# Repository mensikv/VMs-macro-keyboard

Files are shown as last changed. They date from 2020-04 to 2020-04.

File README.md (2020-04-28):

# VM's macro keyboard
This project is developed for Arduino Micro boards and it functions as a **macro keyboard with rotary encoder**. Eight mechanical cherry MX keys can be assigned various functions (writing text, combination and sequences of key codes, multimedia and mouse functions). Rotary encoder supports turning, click and double click.

## Features
* up to 4 keys codes sent at once
* sequence of maximum 16 length of separate key commands
* modifier key to change the default behavior of rotary encoder
* STL files for case
* all keys are directly connected to GPIOs, so no diodes are required
* can emulate keyboard, multimedia key, mouse and system commands

This project is inspired by and some code is taken from [Control volume knob by Prusa](https://blog.prusaprinters.org/3d-print-an-oversized-media-control-volume-knob-arduino-basics/).

## Prerequisites
### Hardware
* 8x [Cherry MX](https://www.aliexpress.com/item/32900957560.html) - I have used red ones
* 1x [25cm micro USB cable](https://www.aliexpress.com/item/32958208619.html) - you can of course use any micro USB cable
* 1x [Arduino Pro Micro 5V](https://www.aliexpress.com/item/32785518952.html) - as the board is powered from the USB, ie. with 5V, you can solder the J1 solder joint to bypass the LDO
* 1x [rotary encoder](https://www.aliexpress.com/item/1000001872933.html) - make sure it has thread to secure it on the case
* Optional - [sillicone wires](https://www.aliexpress.com/item/32872439317.html) - in comparison to my old wires, these are angel's stuff. I have used AWG26, but I suggest to use AWG 28, there are no big currents.

Connection between the components:
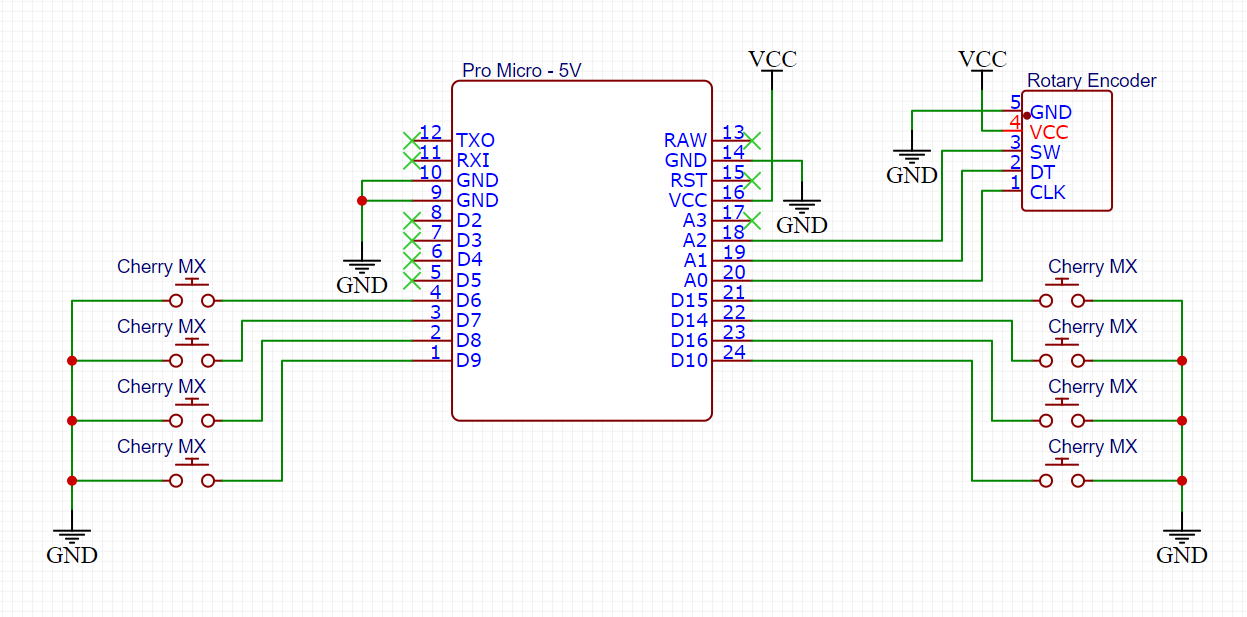
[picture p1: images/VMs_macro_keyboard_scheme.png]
Scheme


### Software
Project was tested with following version:
* Arduino IDE 1.8.12
* Arduino AVR boards 1.8.2

Libraries:
* [ClickEncoder](https://github.com/0xPIT/encoder)
* [TimerOne 1.1](https://github.com/PaulStoffregen/TimerOne)
* [HID-Project 2.6.1](https://github.com/NicoHood/HID)

## Setup
1. Assembly the board and the keys and the rotary encoder according to the [scheme](/images/VMs_macro_keyboard_scheme.png).
1. In Arduino IDE open the sktech `VMs_macro_keyboard.ino`.
1. In section `// Define actions for your keys` define what actions you want to assign to each individual key. There are examples, so inspire from them.
1. In default the rotary encoder functions as volume control, or scrolling (with the modifier key). Click is Pause, double click is Mute. If you want other behavior, tinker with the section `// ROTARY_ACTIONS`.

Bigger part of the arduino Micro memory is taken by array for key commands. If you want to free more memory, either decrease the `MAX_COMBINATION_KEYS` (key codes sent at once) or `MAX_SEQUENCE_KEYS` (length of sequence of commands).

## Supported commands
There are 5 types of key codes the board can send. Each key can be of one type:
### KEYBOARD
Can send common key strokes from any keyboard (letters, SHIFT, CTRL...). The full list of possible key codes is in the file `Arduino\libraries\HID-Project\src\KeyboardLayouts\ImprovedKeylayouts` in the section `enum KeyboardKeycode : uint8_t`. You can define up to 16 combinations each with up to 3 key codes. Each combination can have its own duration. The whole sequence can have up to 3 modifier key codes (for example SHIFT).

### CONSUMER
Can send multimedia and exotic commands. The full list of possible key codes is in the file `Arduino\libraries\HID-Project\src\HID-APIs\ConsumerAPI.h` in the section `enum ConsumerKeycode : uint16_t`. You can define up to 16 combinations each with up to 3 key codes. Each combination can have its own duration.

### SYSTEM
Can send command like *shutdown*, *wake up*. The full list of possible key codes is in the file `Arduino\libraries\HID-Project\src\HID-APIs\SystemAPI.h` in the section `enum SystemKeycode : uint8_t`. Only one command can be defined.

### MOUSE
Can move with the cursor or scroll and click left/right/middle buttons. For syntax see the source code.

### MODIFIER
Changes global variable `globalModifier` so you can use it to assign two functions to one key.

## STL for case
In folder `stl` you will find `*.stl` files for your 3D printer, so you can print nice case for this macro keyboard.
Aside from the provided files you need:
* 8x [KeyV2: Parametric Mechanical Keycap Library](https://www.thingiverse.com/thing:2783650) - I have used oem_row-5_length-1.stl
* 1x [volume knob](https://www.prusaprinters.org/prints/4739-media-control-volume-knob-smooth-knob/files) - I have used knob_smooth_playpause.3mf

More information about the case and photos can be found on [Thingiverse](https://www.thingiverse.com/thing:4322182).

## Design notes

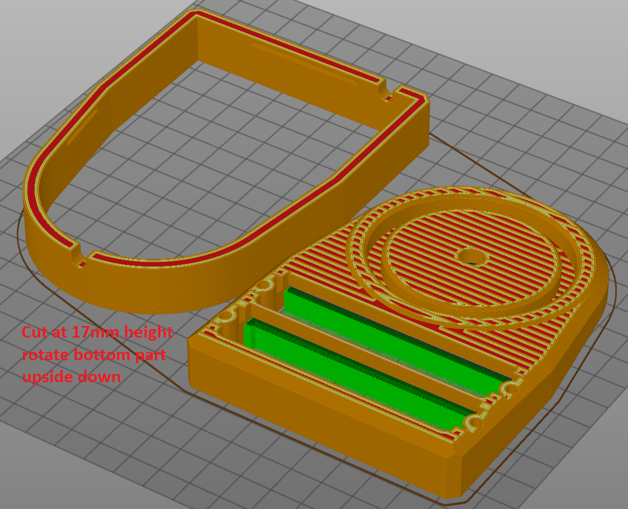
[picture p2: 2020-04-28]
images/VMs_macro_keyboard_slicing_less_support.png

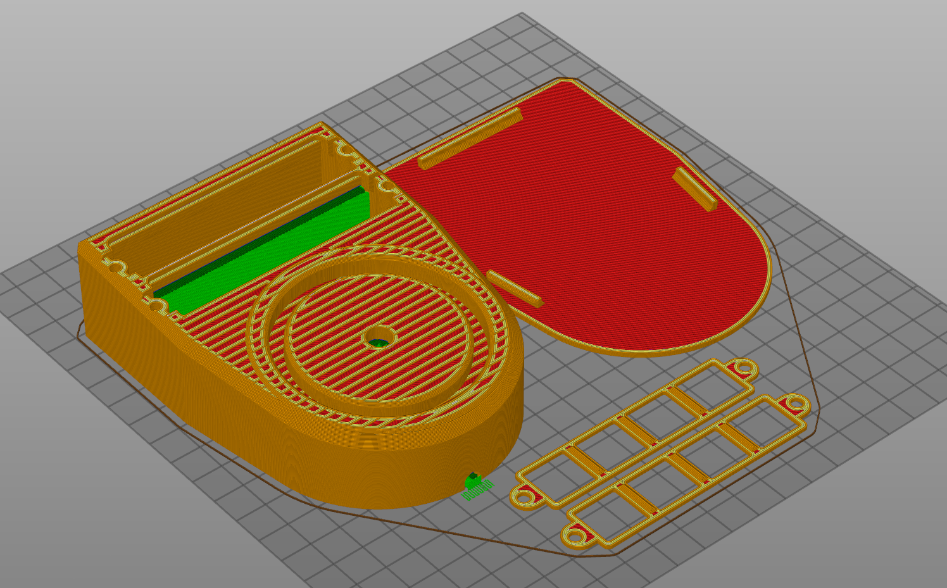
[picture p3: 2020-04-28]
images/VMs_macro_keyboard_slicing.png

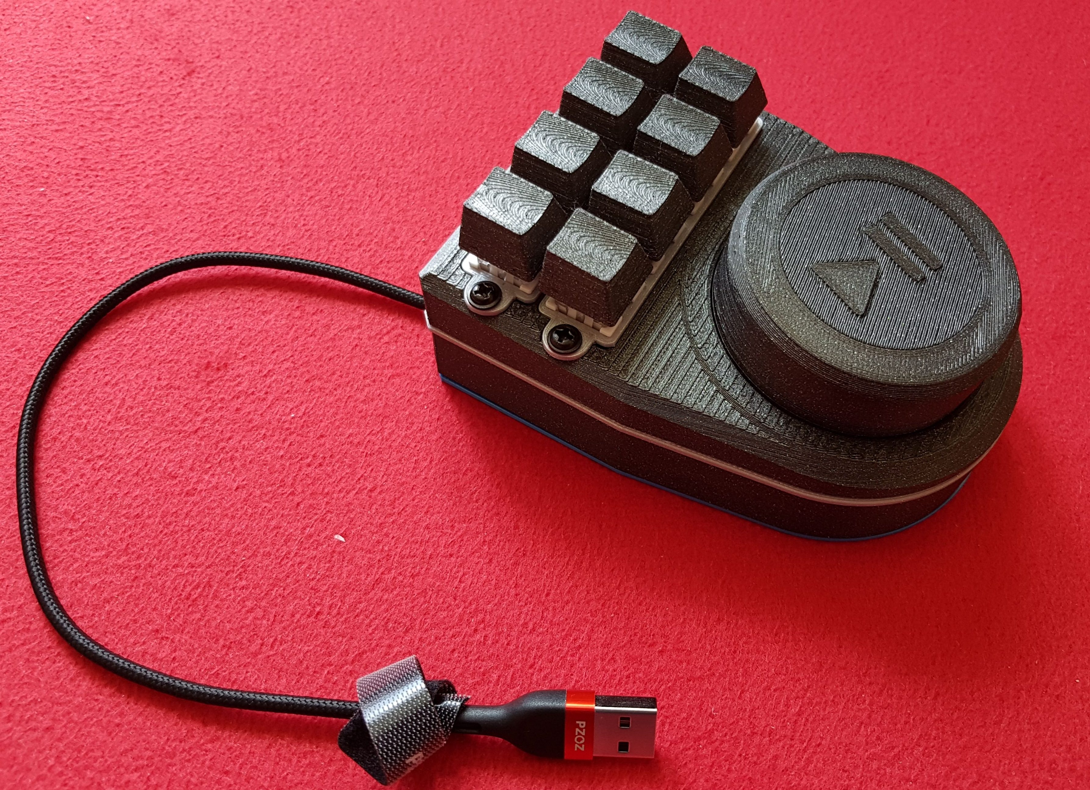
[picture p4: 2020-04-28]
images/VMs_macro_keyboard_case_1.jpg

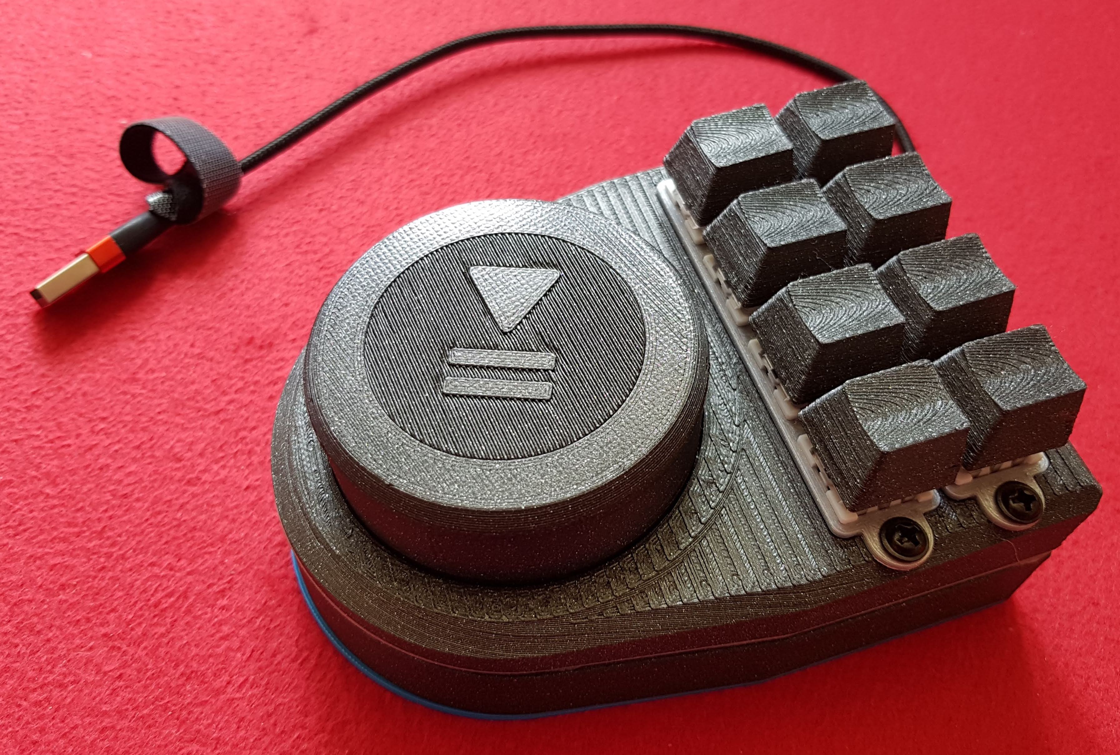
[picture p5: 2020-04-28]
images/VMs_macro_keyboard_case_2.jpg

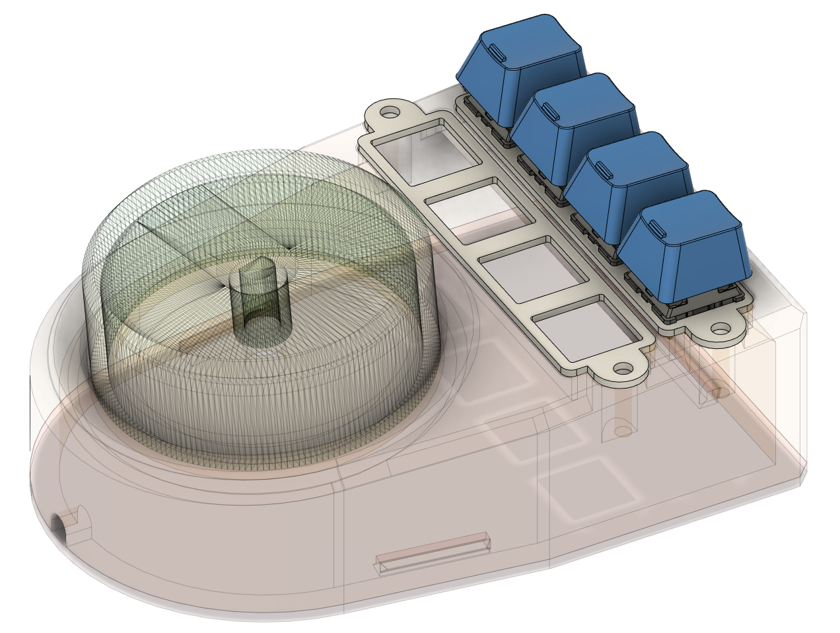
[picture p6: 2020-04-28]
images/VMs_macro_keyboard_fusion360_case_inner.png

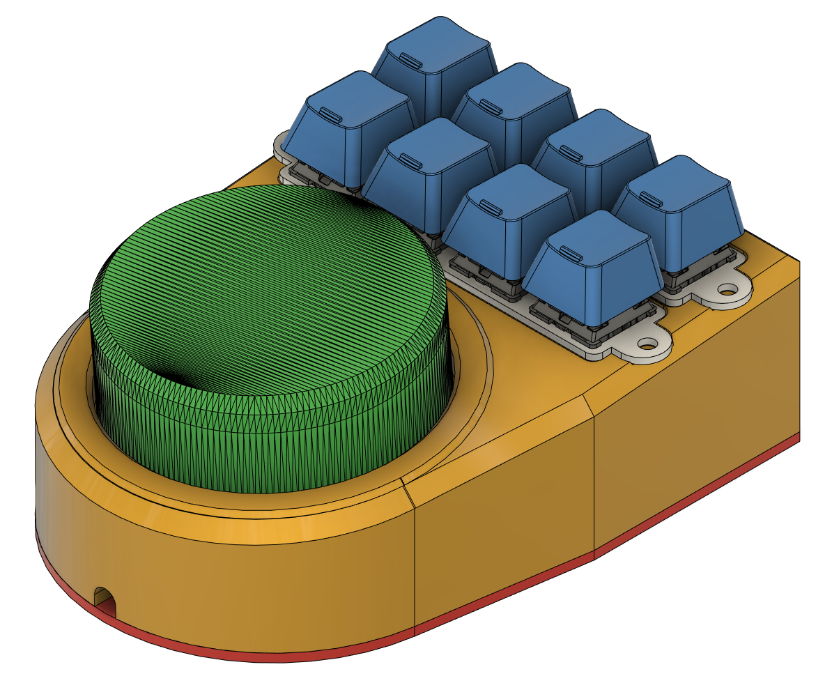
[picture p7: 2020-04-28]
images/VMs_macro_keyboard_fusion360_case.png

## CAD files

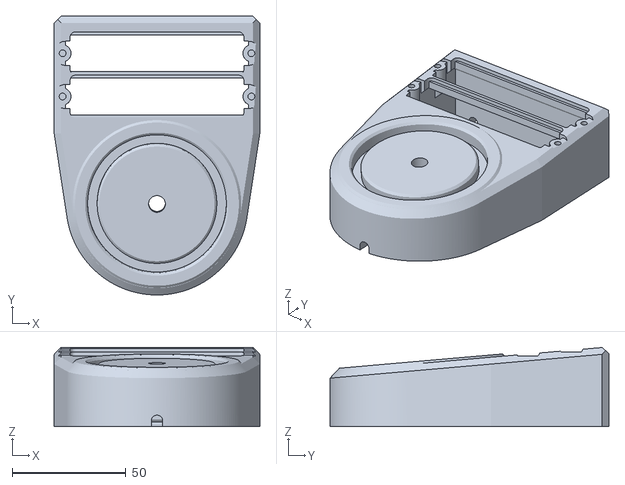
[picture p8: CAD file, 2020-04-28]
stl/VMs_macro_keyboard_case_top.stl
90.4 x 122.7 x 34.7

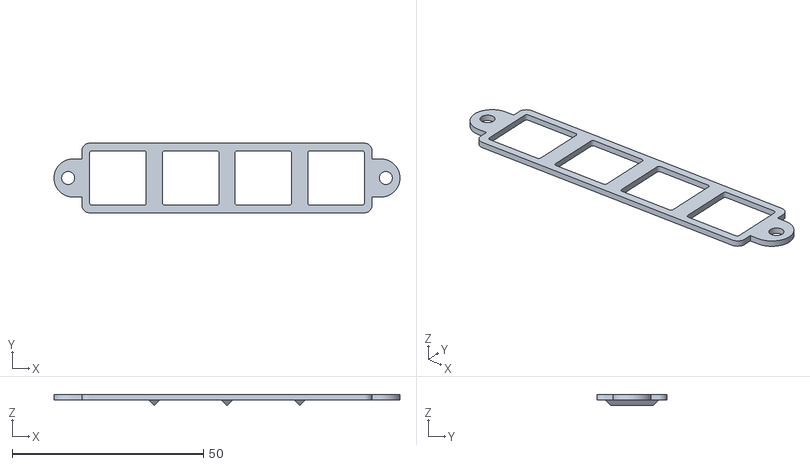
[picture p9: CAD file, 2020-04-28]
stl/VMs_macro_keyboard_key_holder.stl
90.4 x 18.2 x 2.90

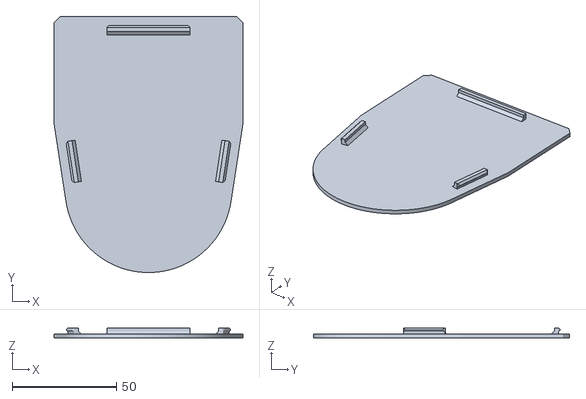
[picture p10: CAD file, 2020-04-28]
stl/VMs_macro_keyboard_case_bottom.stl
90.4 x 122.7 x 5.00

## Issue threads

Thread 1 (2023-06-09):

IDE instructions unclear

littlefrank90, 2023-06-09:
I got the exact models of everything you linked from AliExpress, printed everything that was needed, wired everything like you said.
Now what?
When I plug this Pro Micro board into the USB the IDE won't even recognize the port, so I can't upload anything to it.

mensikv, 2023-06-16:
Hi, I am not sure, if you have any experiences with programming Arduinos. It should be really easy. Open project in Arduino IDE, select the proper board in board manager - Aduino AVR boards > Arduino Pro or Mini. Then connect the board to your computer and select the right Serial port - Tools > Port > Choose the right port.
Then hit upload.

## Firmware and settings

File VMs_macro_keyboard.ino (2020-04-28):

/*
  ####
  ## VM's keyboard
  ####
  Board: Arduino Micro

  Tested with versions:
    Arduino IDE 1.8.12

  Libraries (and version used to develop the project):
    ClickEncoder        - https://github.com/0xPIT/encoder
    TimerOne     v1.1   - https://github.com/PaulStoffregen/TimerOne
    HID-Project  v2.6.1 - https://github.com/NicoHood/HID

  Base on project from Prusa - Volume Control Knob - https://blog.prusaprinters.org/3d-print-an-oversized-media-control-volume-knob-arduino-basics/

  Macro keyboard with rotary encoder. Offers 8 charry MX buttons and one rotary encoder with click.
  The functions of buttons can be set by defining the arrya key.

  If you are unable to upload the code, then briefly connect RST pin to GND when you see "Uploading" in Arduino IDE
*/

#include <Arduino.h>
#include <ClickEncoder.h>
#include <TimerOne.h>
#include <HID-Project.h>



#define NUMBER_OF_KEYS         8    // Count of keys in the keyboard
#define MAX_COMBINATION_KEYS   4    // Maximum number of key codes that can be pressed at the same time (does dont correspond to actually pressed keys)
#define MAX_SEQUENCE_KEYS     16    // Maximum length of key combination sequence (that means first you send CTRL + Z (1. combination), then SHIFT + ALT + X (2. combination), then A (3. combination) ... )

#define DEBOUNCING_MS         20    // wait in ms when key can oscilate
#define FIRST_REPEAT_CODE_MS 500    // after FIRST_REPEAT_CODE_MS ,s if key is still pressed, start sending the command again
#define REPEAT_CODE_MS       150    // when sending command by holding down key, wait this long before sending command egain

// Rotary encoder connections
#define ENCODER_CLK           A0
#define ENCODER_DT            A1
#define ENCODER_SW            A2



// Defining types
enum TKeyState {INACTIVE, DEBOUNCING, ACTIVE, HOLDING};         // Key states - INACTIVE -> DEBOUNCING -> ACTIVE -> HOLDING -> INACTIVE
//                                                                                                               -> INACTIVE
enum TKeyType {KEYBOARD, MOUSE, CONSUMER, SYSTEM, MODIFIER};    // Types of key codes - simulating keyboard, mouse, multimedia or modifier that alters the rotary encoder behavior

typedef struct  TActions {
  uint16_t durationMs;
  uint16_t key[MAX_COMBINATION_KEYS];
} TAction;

typedef struct TKeys {
  uint8_t pin;
  enum TKeyType type;
  enum TKeyState state;
  uint32_t stateStartMs;
  uint16_t modificatorKeys[MAX_COMBINATION_KEYS];
  TAction action[MAX_SEQUENCE_KEYS];
} TKey;
// Different types expect different actions:
//   KEYBOARD - keys + modifiers, for example: {.pin =  8, .type = KEYBOARD, .state = INACTIVE, .stateStartMs = 0, .modificatorKeys = {KEY_LEFT_SHIFT}, .action = {{.durationMs = 100, .key = {KEY_H}}, {.durationMs = 100, .key = {KEY_I}}}}
//   CONSUMER - only keys,        for example: {.pin =  8, .type = KEYBOARD, .state = INACTIVE, .stateStartMs = 0, .modificatorKeys = {}              , .action = {{.durationMs = 100, .key = {MEDIA_VOLUME_MUTE, CONSUMER_BRIGHTNESS_UP}}, {.durationMs = 100, .key = {CONSUMER_CALCULATOR}}}}
//   SYSTEM   - only 1 key,       for example: {.pin =  8, .type = KEYBOARD, .state = INACTIVE, .stateStartMs = 0, .modificatorKeys = {}              , .action = {{.durationMs = 100, .key = {HID_SYSTEM_SLEEPP}}}}
//   MODIFIER - nothing           for example: {.pin =  8, .type = KEYBOARD, .state = INACTIVE, .stateStartMs = 0, .modificatorKeys = {}              , .action = {}}
//   MOUSE    - only keys         for example: {.pin =  8, .type = KEYBOARD, .state = INACTIVE, .stateStartMs = 0, .modificatorKeys = {}              , .action = {{.durationMs = 10100, .key = {10100, 10000, 9800}}, {.durationMs = 200, .key = {MOUSE_LEFT, MOUSE_MIDDLE}}}} = first move 100px in X-direction and scroll -200px and wait 100ms, then click left and middle mouse button and wait 200ms
//                if durationMs >= 10000; then in key is tripplet- delta movement in X, Y and SCROLL (zero is mapped to 10000, so 9800 is -200px) - {{.durationMs = 10200, .key = {10000, 10000, 10300}} - scroll 300px and wait 200ms
//                if durationMs < 10000; then in key are mouse keys to press  - {{.durationMs = 150, .key = {MOUSE_LEFT, MOUSE_MIDDLE}} - press left and middle mouse buttons for 150ms

// Supported key commands:
//  KEYBOARD - c:\Users\XXX\Documents\Arduino\libraries\HID-Project\src\KeyboardLayouts\ImprovedKeylayouts.h - see section enum KeyboardKeycode : uint8_t
//  CONSUMER - c:\Users\XXX\Documents\Arduino\libraries\HID-Project\src\HID-APIs\ConsumerAPI.h               - see section enum ConsumerKeycode : uint16_t
//  SYSTEM   - c:\Users\XXX\Documents\Arduino\libraries\HID-Project\src\HID-APIs\SystemAPI.h                 - see section enum SystemKeycode : uint8_t
//  MOUSE    - c:\Users\XXX\Documents\Arduino\libraries\HID-Project\src\HID-APIs\MouseAPI.h                  - see defines - MOUSE_LEFT, MOUSE_RIGHT, MOUSE_MIDDLE

// Define actions for your keys
TKey key[NUMBER_OF_KEYS] = {
  {.pin =  6, .type = KEYBOARD, .state = INACTIVE, .stateStartMs = 0, .modificatorKeys = {}, .action = {{.durationMs = 50, .key = {KEY_H}}, {.durationMs = 50, .key = {KEY_E}}, {.durationMs = 50, .key = {KEY_L}}, {.durationMs = 50, .key = {KEY_L}}, {.durationMs = 50, .key = {KEY_O}}}},
  {.pin =  7, .type = KEYBOARD, .state = INACTIVE, .stateStartMs = 0, .modificatorKeys = {KEY_LEFT_SHIFT}, .action = {{.durationMs = 50, .key = {KEY_H}}, {.durationMs = 50, .key = {KEY_E}}, {.durationMs = 50, .key = {KEY_L}}, {.durationMs = 50, .key = {KEY_L}}, {.durationMs = 50, .key = {KEY_O}}}},
  {.pin =  8, .type = KEYBOARD, .state = INACTIVE, .stateStartMs = 0, .modificatorKeys = {}, .action = {{.durationMs = 50, .key = {KEY_LEFT_SHIFT, KEY_H}}, {.durationMs = 50, .key = {KEY_E}}, {.durationMs = 50, .key = {KEY_L}}, {.durationMs = 50, .key = {KEY_L}}, {.durationMs = 50, .key = {KEY_O}}}},
  {.pin =  9, .type = KEYBOARD, .state = INACTIVE, .stateStartMs = 0, .modificatorKeys = {}, .action = {{.durationMs = 0, .key = {KEY_LEFT_CTRL, KEY_C}}}},
  {.pin = 15, .type = MODIFIER, .state = INACTIVE, .stateStartMs = 0},
  {.pin = 14, .type = CONSUMER, .state = INACTIVE, .stateStartMs = 0, .modificatorKeys = {}, .action = {{.durationMs = 50, .key = {CONSUMER_CALCULATOR}}}},
  {.pin = 16, .type = SYSTEM,   .state = INACTIVE, .stateStartMs = 0, .modificatorKeys = {}, .action = {{.durationMs = 50, .key = {HID_SYSTEM_HIBERNATE}}}},
  {.pin = 10, .type = MOUSE,   .state = INACTIVE, .stateStartMs = 0, .modificatorKeys = {}, .action = {{.durationMs = 10050, .key = {10050, 10000, 10004}}, {.durationMs = 50, .key = {MOUSE_RIGHT}}}},
};

// Actions for rotary encoder are later in the code (search for ROTARY_ACTIONS)


// global variables
ClickEncoder *encoder;     // variable representing the rotary encoder
int16_t last, value;       // variables for current and last rotation value
uint8_t globalModifier;    // when holding down key with MODIFIER type, this is set to true - can be used to change the behaviour of other keys or rotary encoder


// Capture rotary encoder pulses
void timerIsr() {
  encoder->service();
}

// Execute key commands
uint8_t processKey(uint8_t keyIndex) {
  TKey *lkey = &key[keyIndex];
  if (lkey->type == KEYBOARD) {
    // Press modificators
    for (uint8_t i = 0; i < MAX_COMBINATION_KEYS; i++) {
      if (lkey->modificatorKeys[i]) Keyboard.press((KeyboardKeycode) lkey->modificatorKeys[i]);
      else break;
    }
    for (uint8_t i = 0; i < MAX_SEQUENCE_KEYS; i++) {
      TAction *laction = &lkey->action[i];
      if ((laction->durationMs) || (laction->key[0])) {
        //press keys
        for (uint8_t j = 0; j < MAX_COMBINATION_KEYS; j++) {
          if (laction->key[j]) Keyboard.press((KeyboardKeycode) laction->key[j]);
          else break;
        }
        // wait
        if (laction->durationMs) delay(laction->durationMs);
        //release keys
        for (uint8_t j = 0; j < MAX_COMBINATION_KEYS; j++) {
          if (laction->key[j]) Keyboard.release((KeyboardKeycode) laction->key[j]);
          else break;
        }
      } else {
        break;
      }
    }
    Keyboard.releaseAll();
  } else if (lkey->type == CONSUMER) {
    for (uint8_t i = 0; i < MAX_SEQUENCE_KEYS; i++) {
      TAction *laction = &lkey->action[i];
      if ((laction->durationMs) || (laction->key[0])) {
        //press keys
        for (uint8_t j = 0; j < MAX_COMBINATION_KEYS; j++) {
          if (laction->key[j]) Consumer.press((ConsumerKeycode) laction->key[j]);
          else break;
        }
        // wait
        if (laction->durationMs) delay(laction->durationMs);
        //release keys
        for (uint8_t j = 0; j < MAX_COMBINATION_KEYS; j++) {
          if (laction->key[j]) Consumer.release((ConsumerKeycode) laction->key[j]);
          else break;
        }
      } else {
        break;
      }
    }
    Consumer.releaseAll();
  } else if (lkey->type == SYSTEM) {
    if (lkey->action[0].key[0]) {
      System.write((SystemKeycode) lkey->action[0].key[0]);
    }
    } else if (lkey->type == MOUSE) {
    for (uint8_t i = 0; i < MAX_SEQUENCE_KEYS; i++) {
      // MOUSE - no modifiers,
      // if durationMs >= 10000; then in key is tripplet- delta movement in X, Y and SCROLL (zero is mapped to 10000, so 9800 is -200px) - {{.durationMs = 10200, .key = {10000, 10000, 10300}} - scroll 300px and wait 200ms
      // if durationMs < 10000; then in key are mouse keys to press  - {{.durationMs = 150, .key = {MOUSE_LEFT, MOUSE_MIDDLE}} - press left and middle mouse buttons for 150ms
      TAction *laction = &lkey->action[i];
      if ((laction->durationMs) || (laction->key[0])) {
        if (laction->durationMs < 10000) { // button's clicks
          //press keys
          for (uint8_t j = 0; j < MAX_COMBINATION_KEYS; j++) {
            if (laction->key[j]) Mouse.press((uint8_t) laction->key[j]);
            else break;
          }
          // wait
          if (laction->durationMs) delay(laction->durationMs);
          //release keys
          for (uint8_t j = 0; j < MAX_COMBINATION_KEYS; j++) {
            if (laction->key[j]) Mouse.release((uint8_t) laction->key[j]);
            else break;
          }
        } else {  // cursor movement and scrolling
          int8_t x = laction->key[0] - 10000;
          int8_t y = laction->key[1] - 10000;
          int8_t wheel = laction->key[2] - 10000;
          Mouse.move(x, y, wheel);
          if (laction->durationMs) delay(laction->durationMs - 10000);
        }
      } else {
        break;
      }
    }
    Mouse.releaseAll();
  } else if (lkey->type == MODIFIER) {
    globalModifier = true;
  } else {
    //Serial.println(F("Error - unsupported keyboard type"));
    ;
  }
}

/*
// Serial communication is not started, you must first uncomment it in the setup function
// Print out all keys and their associated commands - good for debugging
void dumpAllKeys () {
  for (uint8_t i = 0; i < NUMBER_OF_KEYS; i++ ) dumpKey(i);
}

// Print out a key's associated commands - good for debugging
void dumpKey (uint8_t keyIndex) {
  TKey *lkey  = &key[keyIndex];
  char msg[100];
  msg[0] = '\0';
  char type[15];
  type[0] = '\0';
  switch (lkey->type) {
    case KEYBOARD: strcpy(type, "KEYBOARD"); break;
    case MOUSE:    strcpy(type, "MOUSE"); break;
    case CONSUMER: strcpy(type, "CONSUMER"); break;
    case SYSTEM:   strcpy(type, "SYSTEM"); break;
    case MODIFIER: strcpy(type, "MODIFIER"); break;
  }
  char state[15];
  state[0] = '\0';
  switch (lkey->state) {
    case INACTIVE:   strcpy(state, "INACTIVE"); break;
    case DEBOUNCING: strcpy(state, "DEBOUNCING"); break;
    case ACTIVE:     strcpy(state, "ACTIVE"); break;
    case HOLDING:    strcpy(state, "HOLDING"); break;
  }
  sprintf(msg, "Key: %i; Pin: %i; Type: %s; State: %s; StartMs: %li\n", keyIndex, lkey->pin, type, state, lkey->stateStartMs);
  Serial.print(msg);
  Serial.print(F("  Modificator keys: "));
  for (uint8_t i = 0; i < MAX_COMBINATION_KEYS; i++) {
    sprintf(msg, "%i, ", lkey->modificatorKeys[i]);
    Serial.print(msg);
  }
  Serial.println();

  for (uint8_t i = 0; i < MAX_SEQUENCE_KEYS; i++) {
    sprintf(msg, "  %i. cmd: DurationMs: %i; Keys: ", i, lkey->action[i].durationMs);
    Serial.print(msg);
    for (uint8_t j = 0; j < MAX_COMBINATION_KEYS; j++) {
      sprintf(msg, "%i, ", lkey->action[i].key[j]);
      Serial.print(msg);
    }
    Serial.println();
  }
  Serial.println();
}
*/

void setup() {
  //Uncomment if you want some debug messages
  //Serial.begin(115200); // Opens the serial connection used for communication with the PC.
  //while (!Serial) delay(1);
  //Serial.println(F("VM's keyboard v0.1"));

  //dumpAllKeys();  // must enable Serial

  Consumer.begin();     // Initializes the media keyboard
  Keyboard.begin();
  Mouse.begin();
  System.begin();

  encoder = new ClickEncoder(ENCODER_DT, ENCODER_CLK, ENCODER_SW); // Initializes the rotary encoder with the mentioned pins

  for (uint8_t i = 0; i < NUMBER_OF_KEYS; i++) pinMode(key[i].pin, INPUT_PULLUP);

  Timer1.initialize(1000);                                         // Initializes the timer, which the rotary encoder uses to detect rotation - 1000us = 1ms
  Timer1.attachInterrupt(timerIsr);

  last = -1;
  globalModifier = false;
}

void loop() {
  // read the key's states and if one is pressed, execute the associated command
  for (uint8_t i = 0; i < NUMBER_OF_KEYS; i++) {
    uint8_t keyState = digitalRead(key[i].pin);
    if ((key[i].state == INACTIVE) && (keyState == LOW)) {
      key[i].state = DEBOUNCING;
      key[i].stateStartMs = millis();
    } else if (key[i].state == DEBOUNCING) {
      if (keyState == HIGH) key[i].stateStartMs = millis();
      else if ((millis() - key[i].stateStartMs) > DEBOUNCING_MS) {
        key[i].state = ACTIVE;
        processKey(i);
      }
    } else if (key[i].state == ACTIVE) {
      if (keyState == HIGH) {
        key[i].state = INACTIVE;
        key[i].stateStartMs = millis();
        if (key[i].type == MODIFIER) {
          globalModifier = false;
        }
      } else if ((millis() - key[i].stateStartMs) > FIRST_REPEAT_CODE_MS) {
        key[i].state = HOLDING;
        key[i].stateStartMs = millis();
        processKey(i);
      }
    } else if (key[i].state == HOLDING) {
      if (keyState == HIGH) {
        key[i].state = INACTIVE;
        key[i].stateStartMs = millis();
        if (key[i].type == MODIFIER) {
          globalModifier = false;
        }
      } else if ((millis() - key[i].stateStartMs) > REPEAT_CODE_MS) {
        key[i].stateStartMs = millis();
        processKey(i);
      }
    }
  }

  // ROTARY_ACTIONS
  // Turning the rotary encoder
  value += encoder->getValue();

  // This part of the code is responsible for the actions when you rotate the encoder
  if (value != last) {                          // New value is different than the last one, that means to encoder was rotated
    uint16_t diff = abs(value - last);
    if (globalModifier) {                       // The rotary encoder is used as volume control or with the Modifier key as a scroll
      signed char wheel = (last < value) ? 4 : -4;
      for (uint8_t i = 0; i < diff; i++) Mouse.move(0, 0, wheel);
    } else {
      ConsumerKeycode cmd = (last < value) ? MEDIA_VOLUME_UP : MEDIA_VOLUME_DOWN;
      for (uint8_t i = 0; i < diff; i++) Consumer.write(cmd);
    }
    last = value;                                 // Refreshing the "last" varible for the next loop with the current value
  }

  // Pressing the rotary encoder - detects single and double clicks
  // This next part handles the rotary encoder BUTTON
  ClickEncoder::Button b = encoder->getButton(); // Asking the button for it's current state
  if (b != ClickEncoder::Open) {                 // If the button is unpressed, we'll skip to the end of this if block
    switch (b) {
      case ClickEncoder::Clicked:                // Button was clicked once
        Consumer.write(MEDIA_PLAY_PAUSE);        // Replace this line to have a different function when clicking button once
        break;
      case ClickEncoder::DoubleClicked:          // Button was double clicked
        Consumer.write(MEDIA_VOLUME_MUTE);       // Replace this line to have a different function when double-clicking
        break;
    }
  }
  //delay(10);                                    // I think this is not needed
}
